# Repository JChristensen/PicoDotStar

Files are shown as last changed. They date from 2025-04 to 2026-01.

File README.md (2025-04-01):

# Pico DotStar Driver  
https://github.com/JChristensen/PicoDotstar  
README file  
Jack Christensen  
Apr-2025

## License
  
This work is licensed under the [Creative Commons Attribution-ShareAlike 4.0 International License](https://creativecommons.org/licenses/by-sa/4.0/).

## Overview
This is just a simple carrier board for a Raspberry Pi Pico and an RTC as I begin working with the Pico. I have a couple old projects that use AVR MCUs to drive DotStar LEDs, so replacing those with Picos sounded fairly straightforward. I added a button, three LEDs, and another header with some GPIO pins, so I may also use the board for general experimentation. Once I figure out the Pico's RTC, a separate RTC may not be needed.

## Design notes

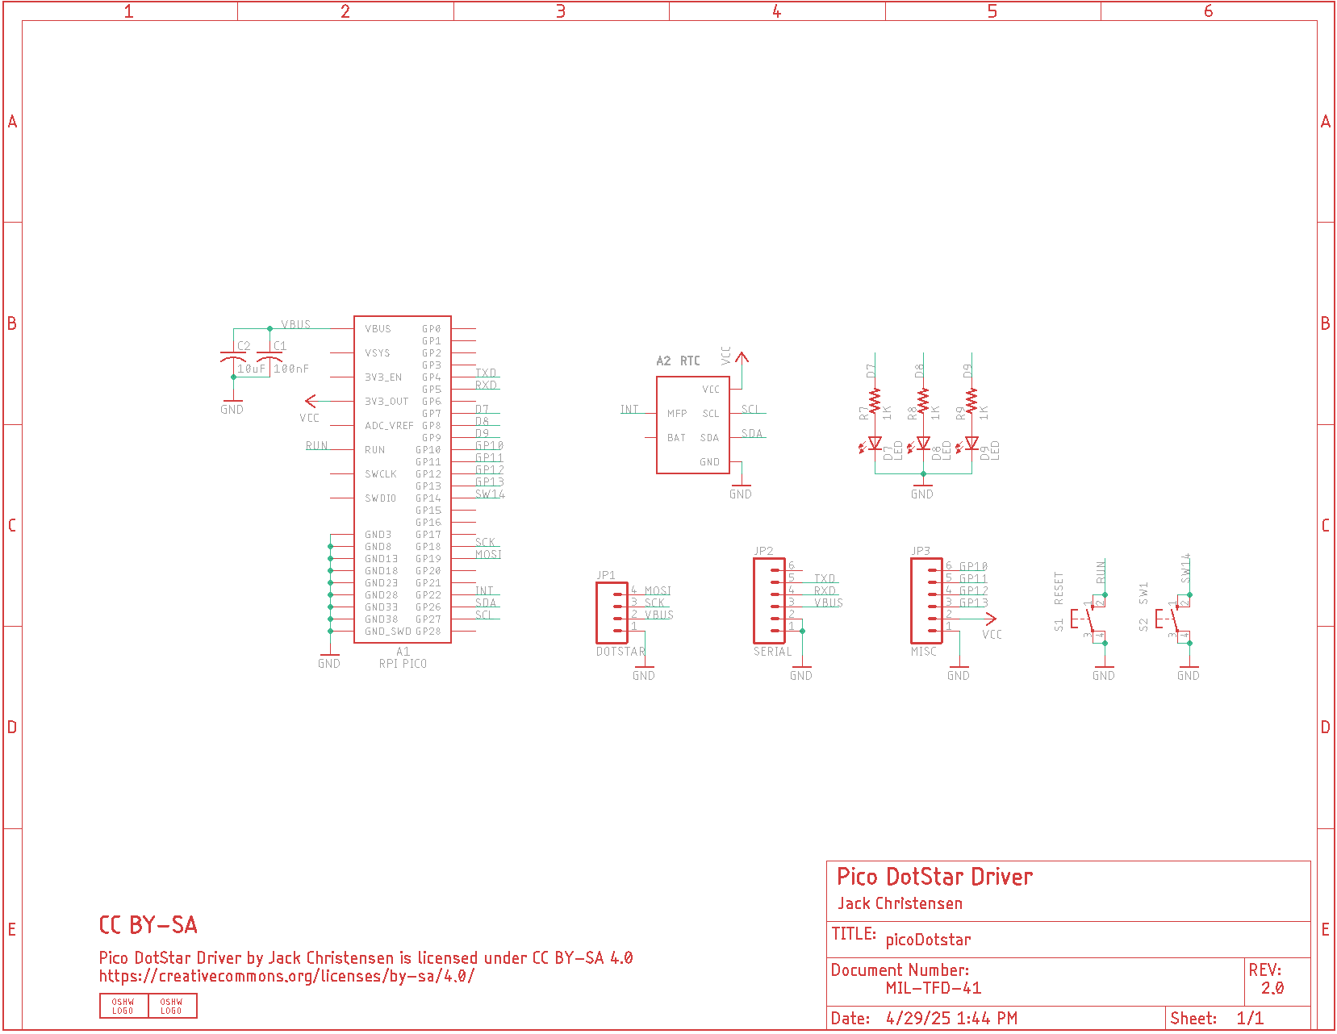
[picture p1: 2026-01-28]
schematic.png

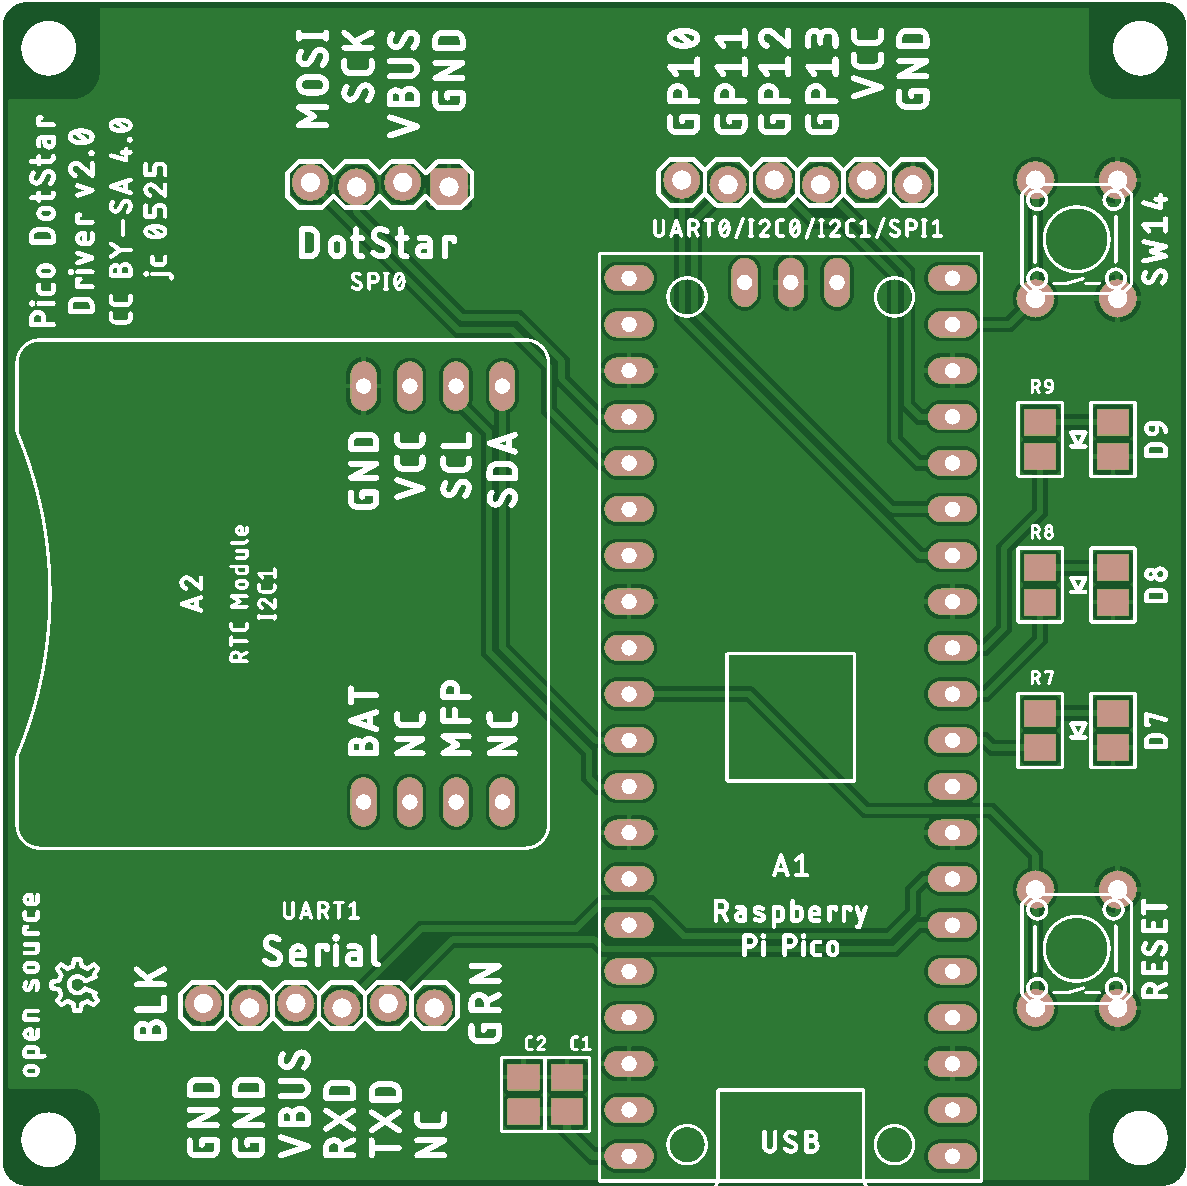
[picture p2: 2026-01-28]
board.png

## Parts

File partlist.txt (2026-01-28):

Partlist

Exported from picoDotstar.sch at 4/29/25 2:34 PM

EAGLE Version 9.6.2 Copyright (c) 1988-2020 Autodesk, Inc.

Assembly variant: 

Part     Value          Device     Package     Library  Sheet

A1       RPI PICO       PICOPICO   PICO        _jc      1
A2       RTC            RTC79412   RTC79412    _jc      1
C1       100nF          C-USM0805  M0805       _jc      1
C2       10uF           C-USM0805  M0805       _jc      1
D7       LED            LEDD0805   D0805       _jc      1
D8       LED            LEDD0805   D0805       _jc      1
D9       LED            LEDD0805   D0805       _jc      1
JP1      DOTSTAR        M04LOCK    1X04_LOCK   SparkFun 1
JP2      SERIAL         M06LOCK    1X06_LOCK   SparkFun 1
JP3      MISC           M06LOCK    1X06_LOCK   SparkFun 1
R7       1K             R-US_M0805 M0805       _jc      1
R8       1K             R-US_M0805 M0805       _jc      1
R9       1K             R-US_M0805 M0805       _jc      1
S1       RESET          10-XXOCT   B3F-10XXOCT _jc      1
S2       SW1            10-XXOCT   B3F-10XXOCT _jc      1

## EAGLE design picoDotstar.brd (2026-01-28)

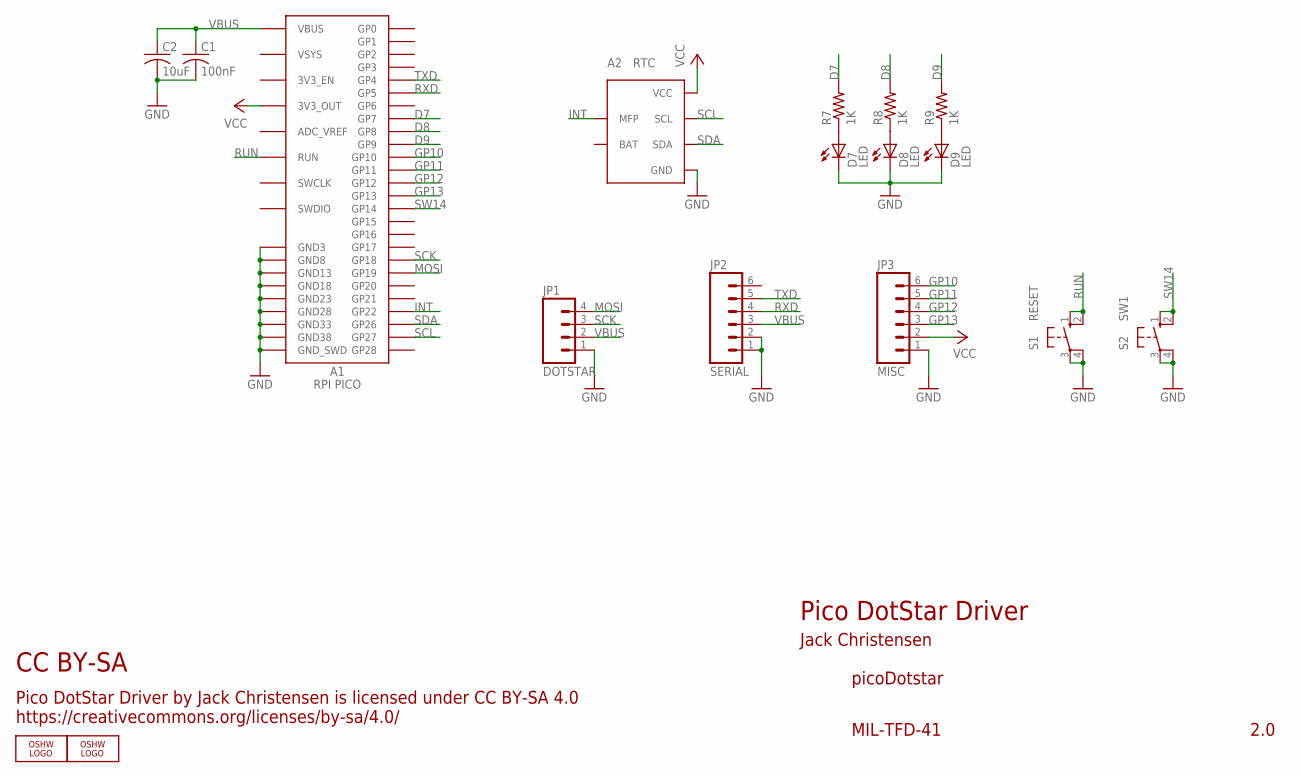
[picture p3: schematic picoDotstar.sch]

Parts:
A1: RPI PICO; PICO
A2: RTC; RTC79412
C1: 100nF; M0805
C2: 10uF; M0805
D7, D8, D9: LED; D0805
JP1: DOTSTAR; 1X04_LOCK
JP2: SERIAL; 1X06_LOCK
JP3: MISC; 1X06_LOCK
LOGO2: OSHW_LOGO_8MILX0100-NT; OSHW_8X100_NOTEXT
LOGO3: OSHW_LOGO_8MILX0150-NT; OSHW_8X150_NOTEXT
R7, R8, R9: 1K; M0805
S1: RESET; B3F-10XXOCT
S2: SW1; B3F-10XXOCT

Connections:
D7: A1.P$10 (GP7), R7.2
D8: A1.P$11 (GP8), R8.2
D9: A1.P$12 (GP9), R9.2
GND: A1.P$03 (GND3), A1.P$08 (GND8), A1.P$13 (GND13), A1.P$18 (GND18), A1.P$23 (GND23), A1.P$28 (GND28), A1.P$33 (GND33), A1.P$38 (GND38), A1.P$SWGND (GND_SWD), A2.8 (GND), C1.2, C2.2, D7.K (C), D8.K (C), D9.K (C), JP1.1, JP2.1, JP2.2, JP3.1, S1.3, S1.4 (P1), S2.3, S2.4 (P1)
GP10: A1.P$14 (GP10), JP3.6
GP11: A1.P$15 (GP11), JP3.5
GP12: A1.P$16 (GP12), JP3.4
GP13: A1.P$17 (GP13), JP3.3
INT: A1.P$29 (GP22), A2.3 (MFP)
MOSI: A1.P$25 (GP19), JP1.4
unnamed: D7.A, R7.1
unnamed: D8.A, R8.1
unnamed: D9.A, R9.1
RUN: A1.P$30 (RUN), S1.1 (S), S1.2 (S1)
RXD: A1.P$07 (GP5), JP2.4
SCK: A1.P$24 (GP18), JP1.3
SCL: A1.P$32 (GP27), A2.6 (SCL)
SDA: A1.P$31 (GP26), A2.5 (SDA)
SW14: A1.P$19 (GP14), S2.1 (S), S2.2 (S1)
TXD: A1.P$06 (GP4), JP2.5
VBUS: A1.P$40 (VBUS), C1.1, C2.1, JP1.2, JP2.3
VCC: A1.P$36 (3V3_OUT), A2.7 (VCC), JP3.2

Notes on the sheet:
MIL-TFD-41
Pico DotStar Driver
Jack Christensen
picoDotstar
2.0
CC BY-SA
Pico DotStar Driver by Jack Christensen is licensed under CC BY-SA 4.0 https://creativecommons.org/licenses/by-sa/4.0/

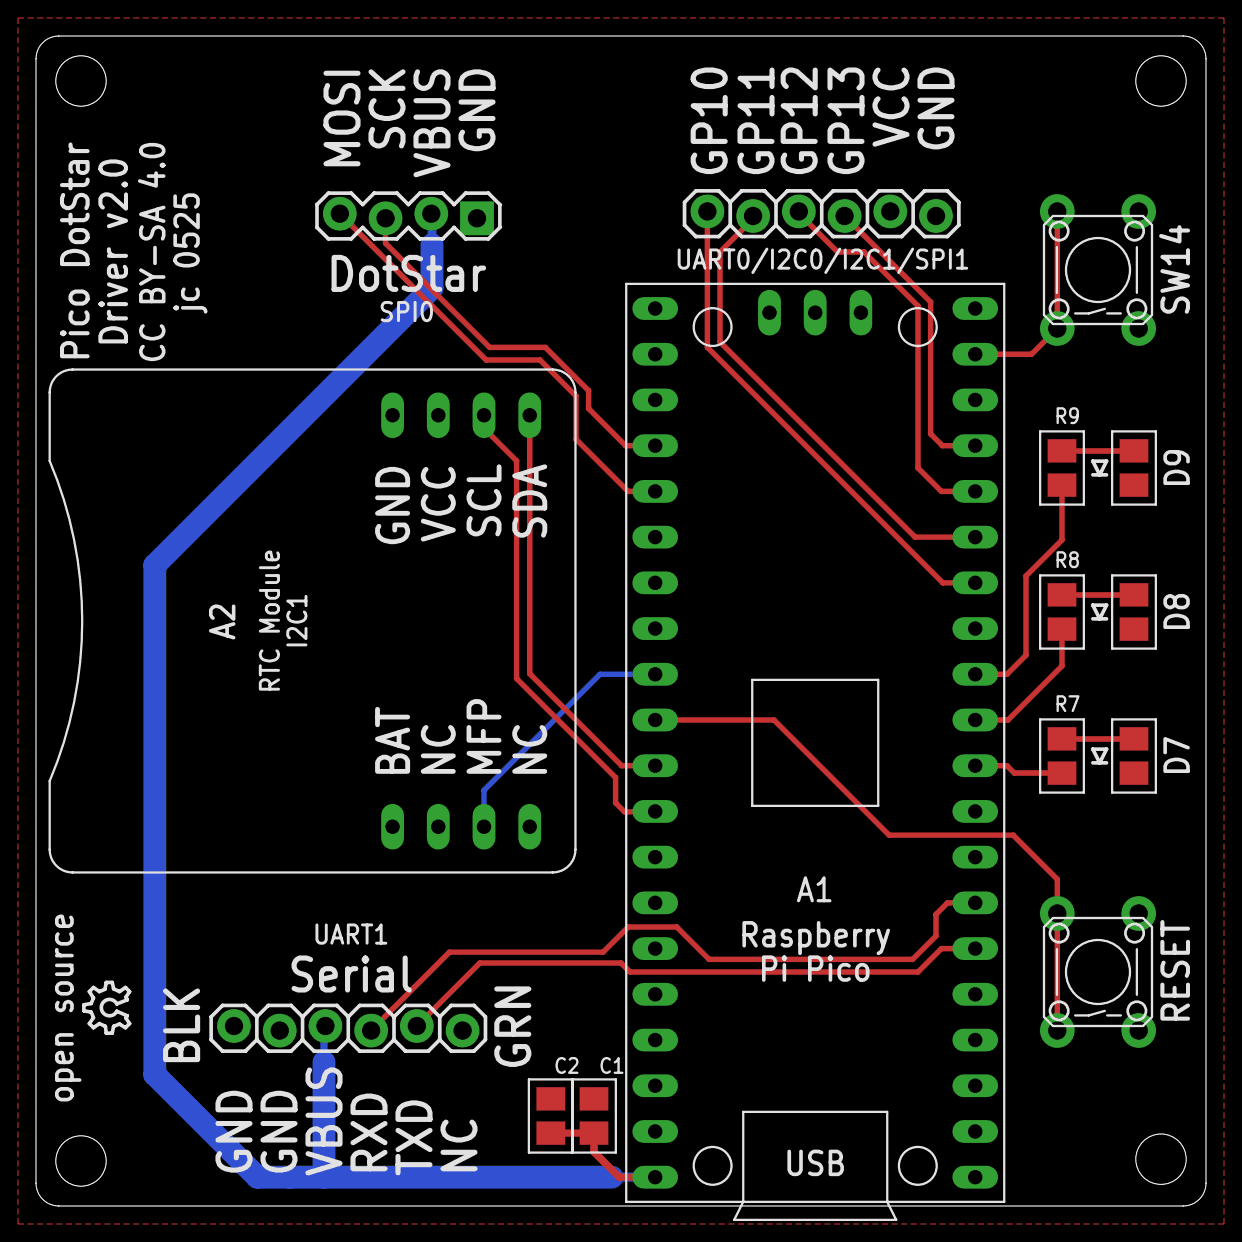
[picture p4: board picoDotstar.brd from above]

Board: 2 copper layers, 65.0 x 65.0 mm, 17 parts (1 on the bottom side), 22 nets.

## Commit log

2025-04-01 Initial commit, v1.0 as sent to fab.
    [picoDotstar.brd, picoDotstar.sch]
2026-01-28 Move RTC from I2C0 to I2C1.
    [picoDotstar.brd, picoDotstar.sch]

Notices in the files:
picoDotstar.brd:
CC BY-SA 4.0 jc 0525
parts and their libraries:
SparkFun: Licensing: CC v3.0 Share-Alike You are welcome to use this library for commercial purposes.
